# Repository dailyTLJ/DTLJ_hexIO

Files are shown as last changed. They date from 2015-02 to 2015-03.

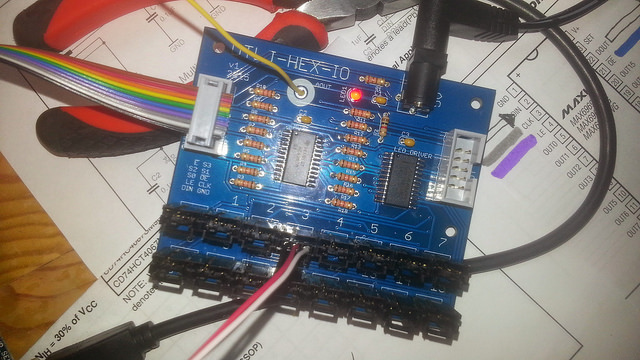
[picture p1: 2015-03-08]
assembled.jpg

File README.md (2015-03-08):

# DTLJ_hexIO

Custom circuit board to connect 16 units of an analog sensor and a LED. Control via a 16-channel Analog Multiplexer and a 16-channel Constant-Current LED driver (+ shifter register). The boards are chainable besides the analog output of the multiplexers. 

v1 has SOIC packages for the two chips, and through-hole packages for all other parts, for easier soldering. 

* 2-layer board
* 3.4 x 2.9 inches
* 35 mil power traces, 20 mil default traces
* 13 mil minimum drill size
* 10 mil clearance btw. traces

<p align="center">
	
</p>

What it looks like assembled

<p align="center">
	
</p>

## Things to change in next iteration

* indicator of LED polarity (on power LED, and sensor-module LEDs)
* analog output pin hole too big

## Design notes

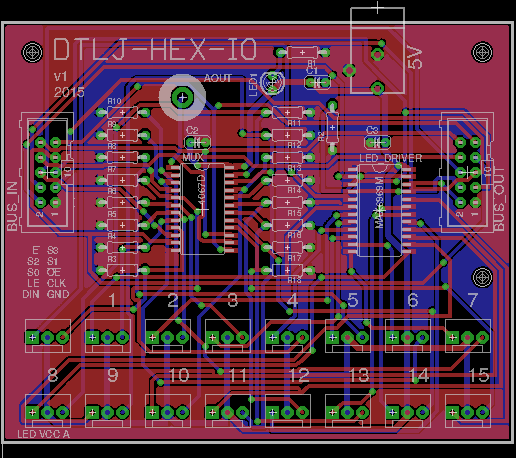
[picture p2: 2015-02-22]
dtlj_hexIO.png

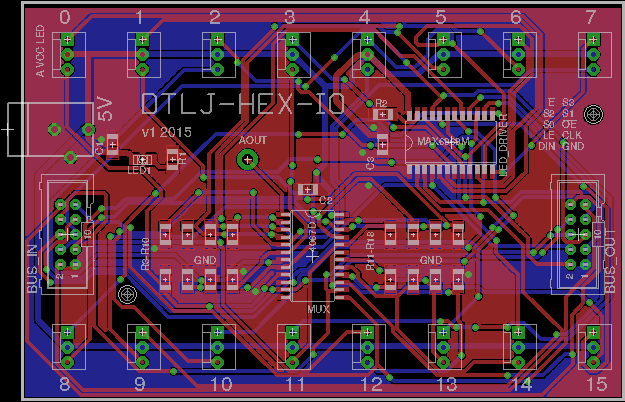
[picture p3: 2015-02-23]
dtlj_hexIO_v2.png

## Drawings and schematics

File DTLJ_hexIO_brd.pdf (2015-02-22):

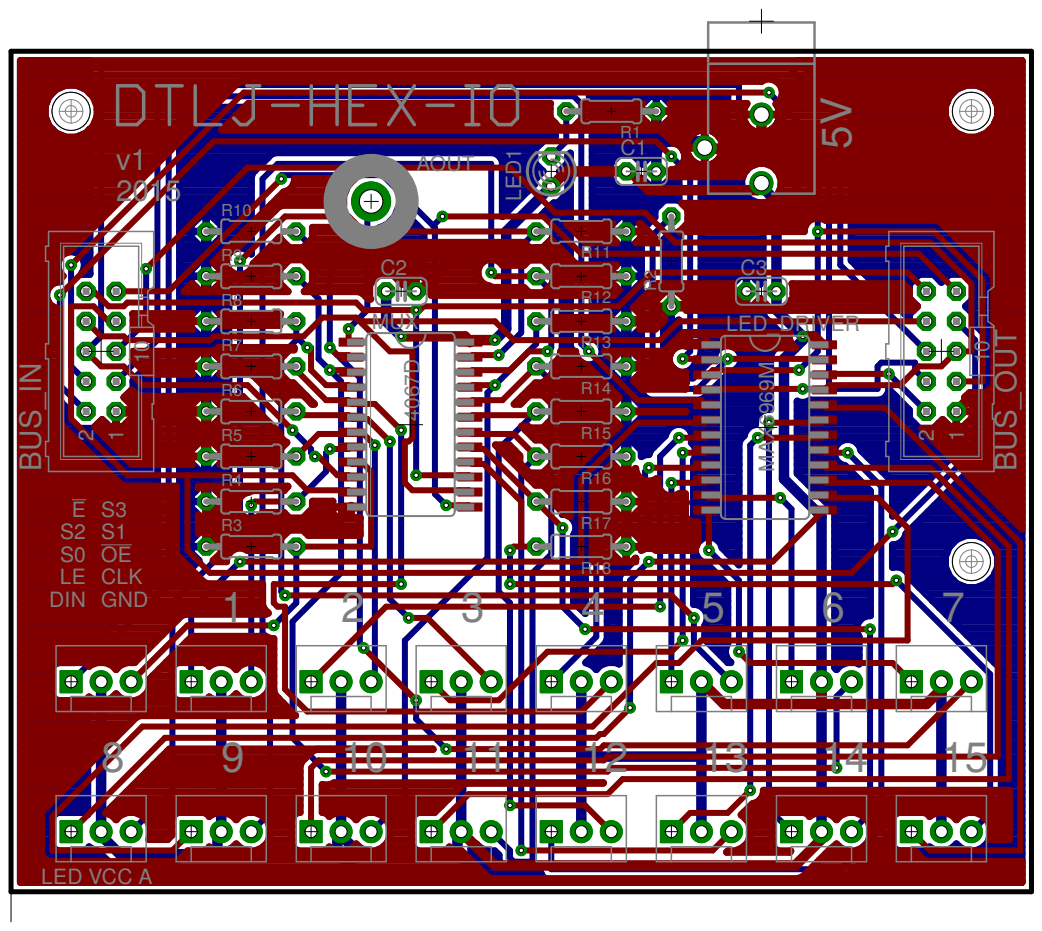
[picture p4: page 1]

v1 | AOUT
2015

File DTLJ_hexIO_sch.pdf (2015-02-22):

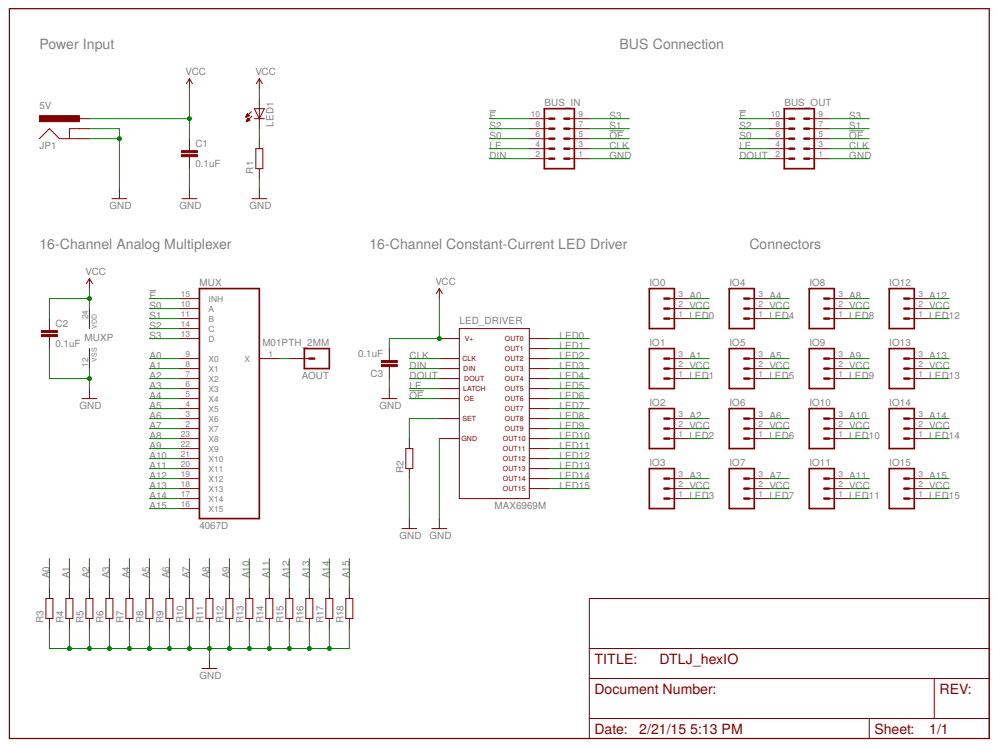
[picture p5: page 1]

Document Number: | REV:

Date: 2/21/15 5:13 PM | Sheet: 1/1

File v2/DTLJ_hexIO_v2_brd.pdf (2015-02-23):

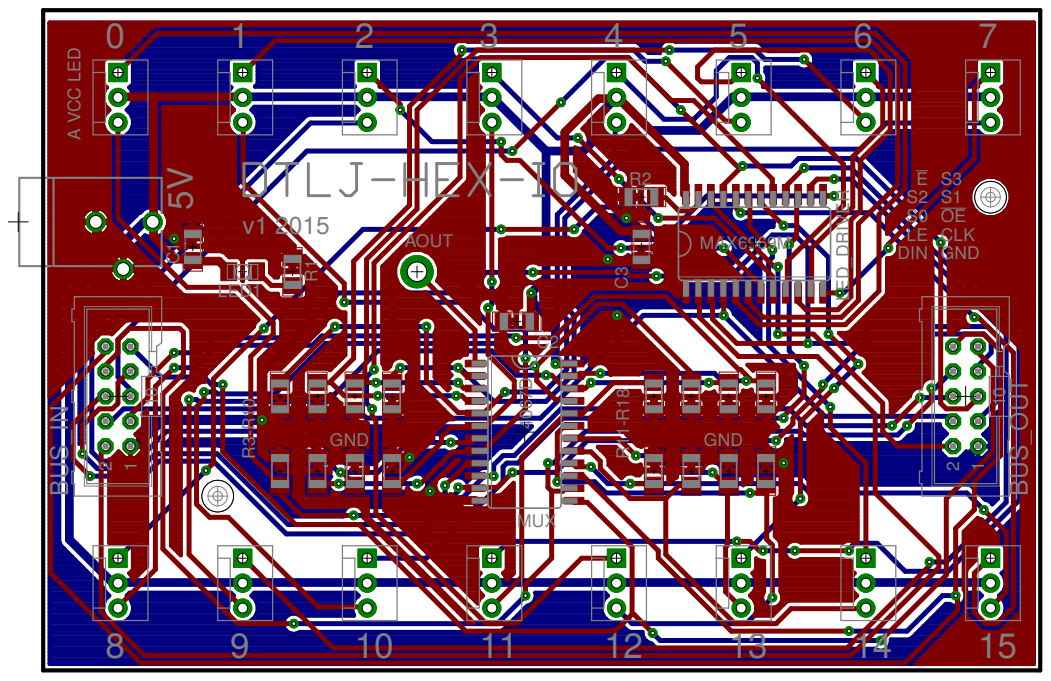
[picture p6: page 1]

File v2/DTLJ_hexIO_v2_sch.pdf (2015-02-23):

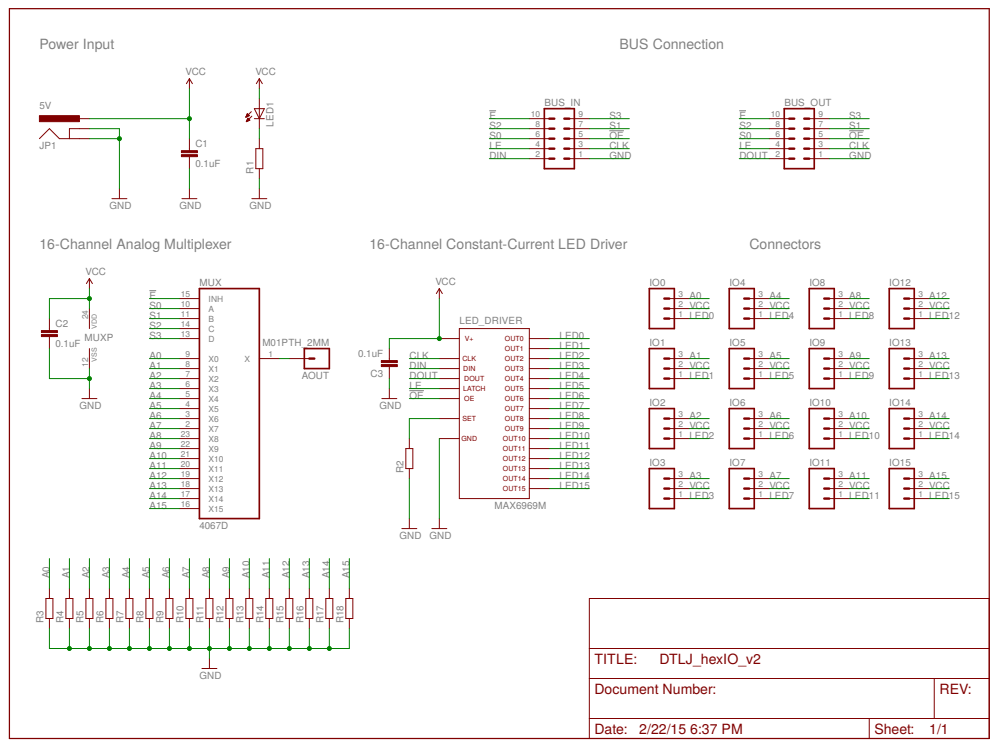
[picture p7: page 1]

Document Number: | REV:

Date: 2/22/15 6:37 PM | Sheet: 1/1

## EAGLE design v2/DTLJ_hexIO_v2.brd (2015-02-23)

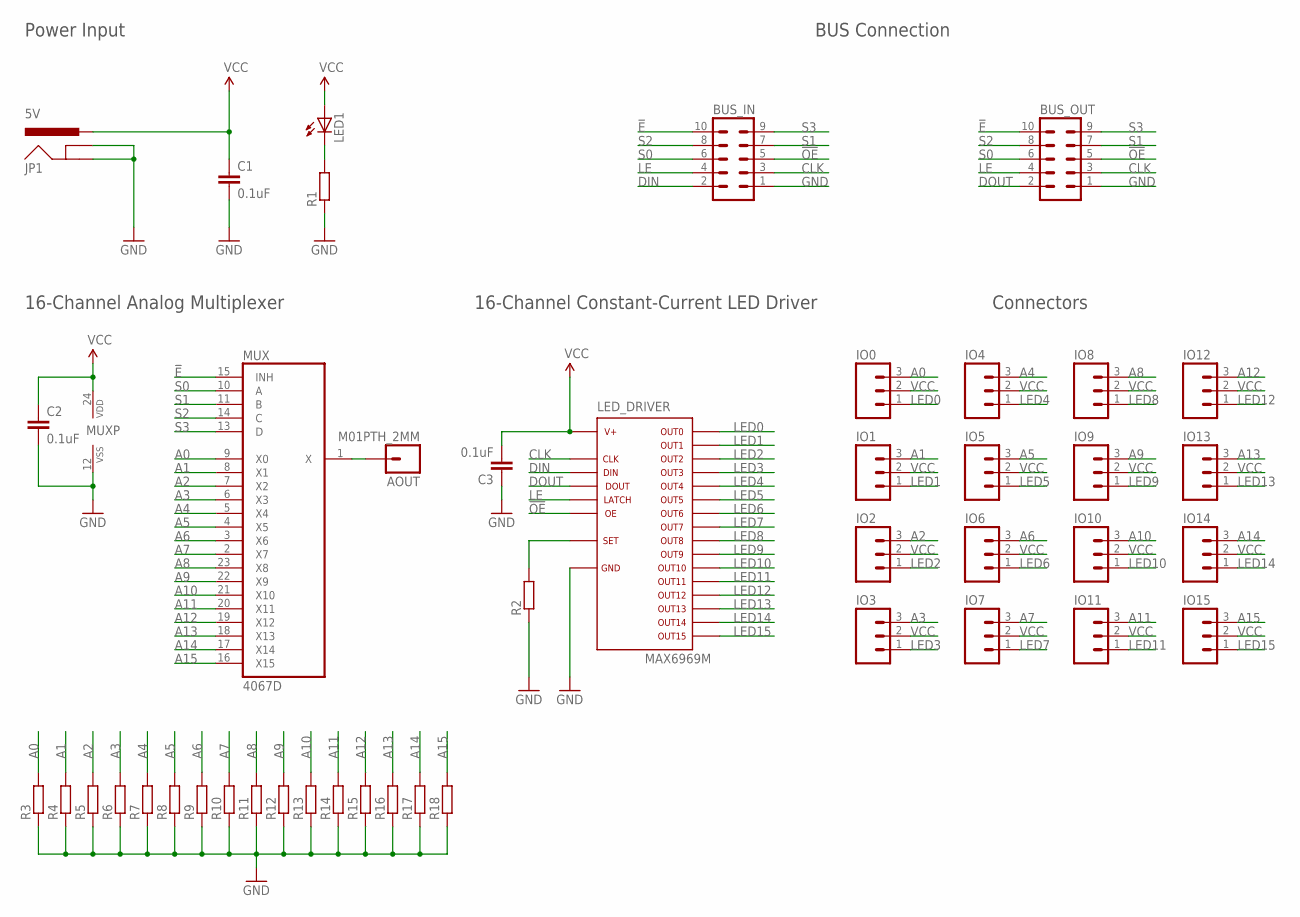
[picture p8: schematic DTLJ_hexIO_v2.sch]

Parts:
AOUT: M01PTH_2MM; 1X01_2MM
BUS_IN: ML10
BUS_OUT: ML10
C1, C2, C3: 0.1uF; C1206
IO0, IO1, IO2, IO3, IO4, IO5, IO6, IO7, IO8, IO9, IO10, IO11, IO12, IO13, IO14, IO15: M03POLAR; MOLEX-1X3
JP1: 5V; POWER_JACK_PTH_BREAD
LED1: LEDSMT1206; 1206
LED_DRIVER: MAX6969M; SO24W
MUX: 4067D; SO24W
R1, R2, R3, R4, R5, R6, R7, R8, R9, R10, R11, R12, R13, R14, R15, R16, R17, R18: R-EU_R1206; R1206

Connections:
!E: BUS_IN.10, BUS_OUT.10, MUX.15 (INH)
!OE: BUS_IN.5, BUS_OUT.5, LED_DRIVER.21
A0: IO0.3, MUX.9 (X0), R3.2
A1: IO1.3, MUX.8 (X1), R4.2
A2: IO2.3, MUX.7 (X2), R5.2
A3: IO3.3, MUX.6 (X3), R6.2
A4: IO4.3, MUX.5 (X4), R7.2
A5: IO5.3, MUX.4 (X5), R8.2
A6: IO6.3, MUX.3 (X6), R9.2
A7: IO7.3, MUX.2 (X7), R10.2
A8: IO8.3, MUX.23 (X8), R11.2
A9: IO9.3, MUX.22 (X9), R12.2
A10: IO10.3, MUX.21 (X10), R13.2
A11: IO11.3, MUX.20 (X11), R14.2
A12: IO12.3, MUX.19 (X12), R15.2
A13: IO13.3, MUX.18 (X13), R16.2
A14: IO14.3, MUX.17 (X14), R17.2
A15: IO15.3, MUX.16 (X15), R18.2
CLK: BUS_IN.3, BUS_OUT.3, LED_DRIVER.3
DIN: BUS_IN.2, LED_DRIVER.2
DOUT: BUS_OUT.2, LED_DRIVER.22
GND: BUS_IN.1, BUS_OUT.1, C1.2, C2.2, C3.1, JP1.GND, JP1.GNDBREAK, LED_DRIVER.1, MUX.12 (VSS), R1.1, R2.1, R3.1, R4.1, R5.1, R6.1, R7.1, R8.1, R9.1, R10.1, R11.1, R12.1, R13.1, R14.1, R15.1, R16.1, R17.1, R18.1
LE: BUS_IN.4, BUS_OUT.4, LED_DRIVER.4
LED0: IO0.1, LED_DRIVER.5
LED1: IO1.1, LED_DRIVER.6
LED2: IO2.1, LED_DRIVER.7
LED3: IO3.1, LED_DRIVER.8
LED4: IO4.1, LED_DRIVER.9
LED5: IO5.1, LED_DRIVER.10
LED6: IO6.1, LED_DRIVER.11
LED7: IO7.1, LED_DRIVER.12
LED8: IO8.1, LED_DRIVER.13
LED9: IO9.1, LED_DRIVER.14
LED10: IO10.1, LED_DRIVER.15
LED11: IO11.1, LED_DRIVER.16
LED12: IO12.1, LED_DRIVER.17
LED13: IO13.1, LED_DRIVER.18
LED14: IO14.1, LED_DRIVER.19
LED15: IO15.1, LED_DRIVER.20
unnamed: LED1.C, R1.2
unnamed: LED_DRIVER.23, R2.2
unnamed: AOUT.1, MUX.1 (X)
S0: BUS_IN.6, BUS_OUT.6, MUX.10 (A)
S1: BUS_IN.7, BUS_OUT.7, MUX.11 (B)
S2: BUS_IN.8, BUS_OUT.8, MUX.14 (C)
S3: BUS_IN.9, BUS_OUT.9, MUX.13 (D)
VCC: C1.1, C2.1, C3.2, IO0.2, IO1.2, IO2.2, IO3.2, IO4.2, IO5.2, IO6.2, IO7.2, IO8.2, IO9.2, IO10.2, IO11.2, IO12.2, IO13.2, IO14.2, IO15.2, JP1.PWR, LED1.A, LED_DRIVER.24, MUX.24 (VDD)

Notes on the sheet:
Power Input
BUS Connection
16-Channel Analog Multiplexer
16-Channel Constant-Current LED Driver
Connectors

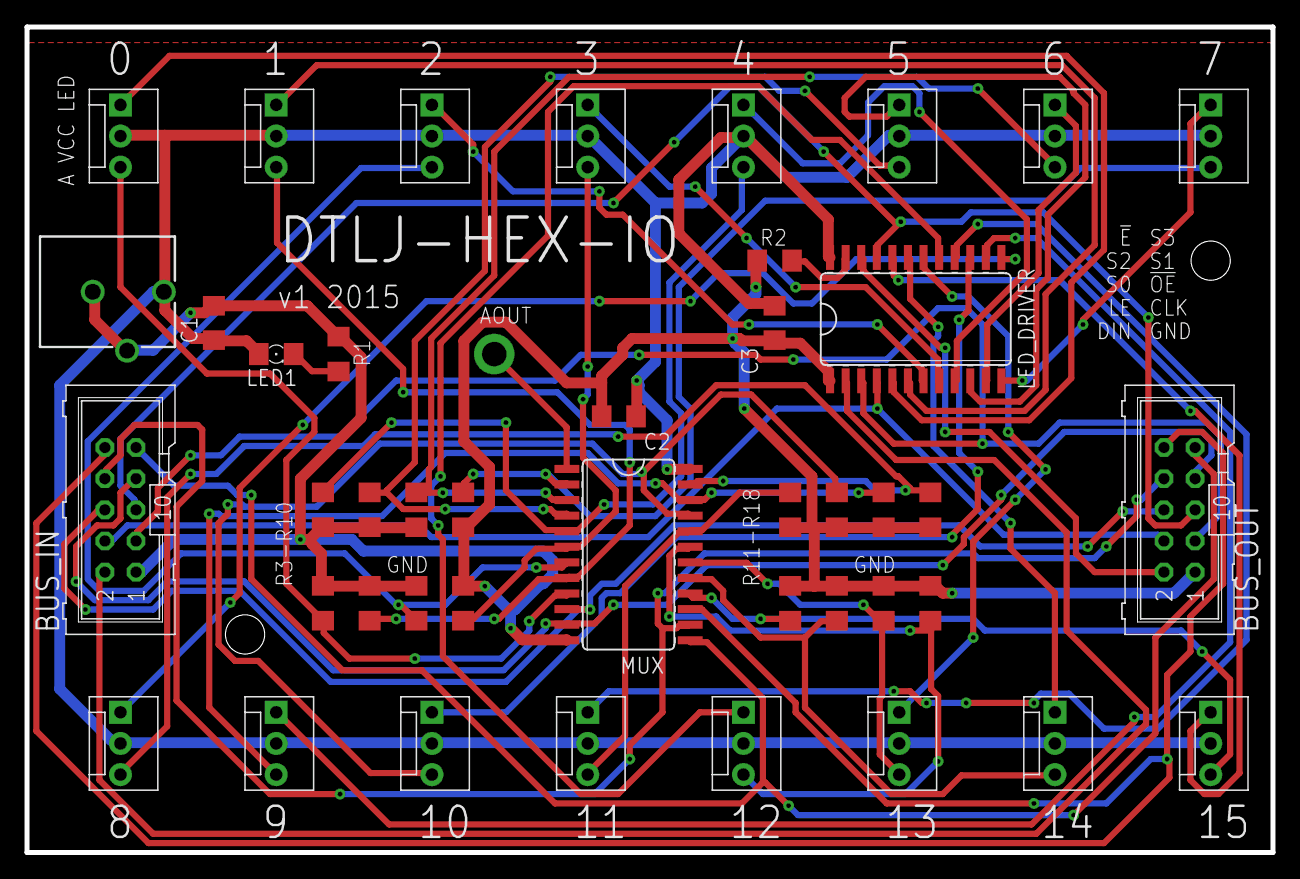
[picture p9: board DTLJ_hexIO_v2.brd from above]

Board: 2 copper layers, 101.6 x 67.3 mm, 44 parts (0 on the bottom side), 47 nets.

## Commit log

2015-02-22 ready for a first round of Golden Phoenix
    [DTLJ_hexIO.brd, DTLJ_hexIO.sch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]
2015-02-23 v2 = smd version
    [DTLJ_hexIO_v2.brd, DTLJ_hexIO_v2.sch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]
2015-03-08 assembled pic

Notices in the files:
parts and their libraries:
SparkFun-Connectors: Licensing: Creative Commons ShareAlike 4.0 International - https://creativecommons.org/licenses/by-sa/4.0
